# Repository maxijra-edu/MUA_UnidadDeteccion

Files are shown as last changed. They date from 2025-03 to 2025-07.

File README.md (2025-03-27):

# MUA_UnidadDeteccion

Repositorio del proyecto de la Unidad de Detección de la Misión MUA para el GuaraniSat-2, desarrollado en el LME de la FIUNA.

Carpetas:

- Comunicación_Arduino: Contiene el proyecto de platform.io para la comunicación con los componentes digitales de la placa.
- Modelos_3D: Contiene los proyectos FreeCAD (0.21.2) de los modelos de la carcasa, los espaciadores y el ensamble.
- Placa_DetectorParticulas: Proyecto KiCAD (7.0) de la placa principal de la unida de detección.
- Placa_SiPM: Proyecto KiCAD (7.0) del PCB interfaz de los SiPM.

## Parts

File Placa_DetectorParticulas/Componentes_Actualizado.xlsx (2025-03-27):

# | Reference | Qty | Value | Footprint | DNP
1 | C1, C33 | 2 | 0.47uF | Capacitor_SMD:C_0603_1608Metric
2 | C2, C5, C34, C37 | 4 | 1uF | Capacitor_SMD:C_1206_3216Metric
3 | C3, C35 | 2 | 220nF | Capacitor_SMD:C_0603_1608Metric
4 | C4, C36 | 2 | 100nF | Capacitor_SMD:C_0603_1608Metric
5 | C6, C7, C12, C13, C20, C23 | 6 | 10nF | Capacitor_SMD:C_0805_2012Metric
6 | C8, C17 | 2 | 15p | Capacitor_SMD:C_0805_2012Metric
7 | C9, C15, C18, C19, C21, C22, C24, C25, C26, C27, C29, C30, C32, C38, C39, C40, C41, C42, C43, C44, C45, C50, C53, C55 | 24 | 100nF | Capacitor_SMD:C_0805_2012Metric
8 | C10, C16 | 2 | 10u | Capacitor_SMD:C_0805_2012Metric
9 | C11, C14 | 2 | 270p | Capacitor_SMD:C_0805_2012Metric
10 | C28, C31 | 2 | 0.015uF | Capacitor_SMD:C_0805_2012Metric
11 | C46, C47 | 2 | 3p | Capacitor_SMD:C_0805_2012Metric
12 | C48, C49 | 2 | 1uF | Capacitor_SMD:C_0805_2012Metric
13 | C51, C52, C54, C56 | 4 | 6.8uF | Capacitor_SMD:C_0805_2012Metric
14 | D1, D2 | 2 | BAT46 | Diode_SMD:D_SOD-123
15 | D3, D4 | 2 | LED | LED_SMD:LED_0603_1608Metric
16 | J1, J2, J3, J4 | 4 | Conn_02x08_Odd_Even | Connector_PinHeader_2.54mm:PinHeader_2x08_P2.54mm_Vertical
17 | L1, L3 | 2 | 82uH | Inductor_SMD:L_1812_4532Metric
18 | L2, L4 | 2 | 220uH | Inductor_SMD:L_1210_3225Metric
19 | Q1, Q2 | 2 | BSS123 | Package_TO_SOT_SMD:TSOT-23
20 | R1, R44 | 2 | 10k | Resistor_SMD:R_0603_1608Metric
21 | R2, R11, R24, R25, R26, R27, R28, R29, R32, R34, R38, R54, R55, R56, R57, R59, R60, R61, R62, R64, R65 | 21 | 1k | Resistor_SMD:R_0805_2012Metric
22 | R3, R46 | 2 | 392R | Resistor_SMD:R_0603_1608Metric
23 | R4 | 1 | 6.8k | Resistor_SMD:R_0805_2012Metric
24 | R5, R48 | 2 | 240k | Resistor_SMD:R_0603_1608Metric
25 | R6, R15 | 2 | 50 | Resistor_SMD:R_0805_2012Metric
26 | R7, R9, R20, R21 | 4 | 10 | Resistor_SMD:R_0805_2012Metric
27 | R8, R13 | 2 | 5 | Resistor_SMD:R_0805_2012Metric
28 | R10, R12, R72, R73 | 4 | 470 | Resistor_SMD:R_0805_2012Metric
29 | R14 | 1 | 4.53k | Resistor_SMD:R_0805_2012Metric
30 | R16 | 1 | 5.1k | Resistor_SMD:R_0805_2012Metric
31 | R17 | 1 | 68k | Resistor_SMD:R_0805_2012Metric
32 | R18 | 1 | 57.6k | Resistor_SMD:R_0805_2012Metric
33 | R19, R22, R30, R31, R42, R45, R47, R50, R52, R68, R69, R77 | 12 | 10k | Resistor_SMD:R_0805_2012Metric
34 | R23, R35, R39, R53 | 4 | 100k | Resistor_SMD:R_0805_2012Metric
35 | R33, R37 | 2 | 1.5k | Resistor_SMD:R_0805_2012Metric
36 | R36, R40 | 2 | 47 | Resistor_SMD:R_0805_2012Metric
37 | R41, R49, R74, R75, R76, R78 | 6 | 24.9k | Resistor_SMD:R_0603_1608Metric
38 | R43, R51 | 2 | 12.4k | Resistor_SMD:R_0603_1608Metric
39 | R58, R63, R66, R67, R70, R71 | 6 | 0 | Resistor_SMD:R_0805_2012Metric
40 | U1, U20 | 2 | max1932etc+T | 0A_MAX1932:21-0139_T1244&plus_4_MXM
41 | U2, U4 | 2 | OPA855QDSGRQ1 | 0A_OPA855QDSGRQ1:WSON8_DSG_TEX
42 | U3, U5, U9, U23 | 4 | TSZ122IQ2T | 0A_TSZ122IQ2T:DFN8_2X2_NB_STM
43 | U6, U7 | 2 | TS3011IYQ3T | 0A_TS3011IYQ3T:dfn8_2p06x2p06x0p5_stm
44 | U8 | 1 | MCP4561T-104E/MF | DFN8_3x3MC_MCH
45 | U10, U12 | 2 | SN74LV1T04QDCKRQ1 | 0A_SN74LV1T04QDCKRQ1:SC70-5_DCK_TEX
46 | U11, U13 | 2 | 74LVC2G00DP_125 | 0A_74LVC2G00DP-Q100H:SOT765-1_NEX
47 | U14 | 1 | TMP100AQDBVRQ1 | 0A_TMP100AQDBVRQ1:DBV6_TEX
48 | U15, U16 | 2 | ~ | 0A_SiPM_Board:SiPM_Board
49 | U17 | 1 | ~ | 0A_Centellador:Centellador_X2
50 | U18 | 1 | NXS0108BQ-Q100X | 0A_NXS0108BQ-Q100X:DHVQFN20_SOT764-1_NEX
51 | U19 | 1 | NXB0108BQ-Q100X | 0A_NXB0108BQ-Q100X:DHVQFN20_SOT764-1_NEX
52 | U21, U25 | 2 | ADR5044WBRTZ-R7 | 0A_ADR5044WBRTZ-R7:RT_3_ADI
53 | U22, U24 | 2 | INA148QDRQ1 | 0A_INA148QDRQ1:D8
54 | U26, U28 | 2 | DAC8551AQDGKRQ1 | 0A_DAC8551AQDGKRQ1:DGK8_TEX
55 | U27 | 1 | ADR5041WBRTZ-R7 | 0A_ADR5041WBRTZ_R7:RT_3_ADI

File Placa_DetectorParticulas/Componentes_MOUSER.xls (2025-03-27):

SHOPPING CART
This is not an invoice
27-Mar-25 13:32:36
 | Mouser # | Mfr. # | Manufacturer | Customer # | Description | RoHS | Lifecycle | Order Qty. | Price (USD) | Ext.: (USD)
1 | 80-C0805C150J5GAUTO | C0805C150J5GACAUTO | KEMET |  | Multilayer Ceramic Capacitors MLCC - SMD/SMT 50V 15pF C0G 0805 5% AEC-Q200 | RoHS Compliant |  | 10 | $0.101 | $1.01
2 | 80-C0805C200J1HAUTO | C0805C200J1HACAUTO | KEMET |  | Multilayer Ceramic Capacitors MLCC - SMD/SMT 100V 20pF X8R 0805 5% AEC-Q200 | RoHS Compliant |  | 10 | $0.053 | $0.53
3 | 81-GCM188R71C474KA5J | GCM188R71C474KA55J | Murata |  | Multilayer Ceramic Capacitors MLCC - SMD/SMT 0.47 uF 16 VDC 10% 0603 X7R AEC-Q200 | RoHS Compliant |  | 10 | $0.089 | $0.89
4 | 963-HMK316B7105KLHT | HMK316B7105KLHT | TAIYO YUDEN |  | Multilayer Ceramic Capacitors MLCC - SMD/SMT 963-MCASH31LSB7105KT RPLCMT PN 100V 1uF X7R 1206 AEC-Q200 | RoHS Compliant |  | 10 | $0.241 | $2.41
5 | 963-MAASU168AC7224KT | MAASU168AC7224KTCA01 | TAIYO YUDEN |  | Multilayer Ceramic Capacitors MLCC - SMD/SMT 50V 0.22uF X7S 0603 10% AEC-Q200 | RoHS Compliant |  | 10 | $0.124 | $1.24
6 | 581-KAM15AR71H104KM | KAM15AR71H104KM | KYOCERA AVX |  | Multilayer Ceramic Capacitors MLCC - SMD/SMT 50V .1uF X7R 0603 10 % AEC-Q200 | RoHS Compliant | New Product | 20 | $0.264 | $5.28
7 | 581-KAF21BR72A103JT | KAF21BR72A103JT | KYOCERA AVX |  | Multilayer Ceramic Capacitors MLCC - SMD/SMT 100V .01uF X7R 0805 5% AEC-Q200 FLEXITER | RoHS Compliant | New Product | 10 | $0.195 | $1.95
8 | 581-KAM21BR71H104JT | KAM21BR71H104JT | KYOCERA AVX |  | Multilayer Ceramic Capacitors MLCC - SMD/SMT 50V .1uF X7R 0805 5% AEC-Q200 | RoHS Compliant | New Product | 40 | $0.208 | $8.32
9 | 810-CGA4J1X7R0J106K | CGA4J1X7R0J106K125AC | TDK |  | Multilayer Ceramic Capacitors MLCC - SMD/SMT CGA 0805 6.3V 10uF X7R 10% AEC-Q200 | RoHS Compliant |  | 16 | $0.18 | $2.88
10 | 80-C0805C271J5GAUTO | C0805C271J5GACAUTO | KEMET |  | Multilayer Ceramic Capacitors MLCC - SMD/SMT 50V 270pF C0G 0805 5% AEC-Q200 | RoHS Compliant |  | 10 | $0.202 | $2.02
11 | 80-C0805C153J5RAUTO | C0805C153J5RACAUTO | KEMET |  | Multilayer Ceramic Capacitors MLCC - SMD/SMT 50V 0.015uF X7R 0805 5% AEC-Q200 | RoHS Compliant |  | 10 | $0.276 | $2.76
12 | 80-C0603C309C4HAUTO | C0603C309C4HACAUTO | KEMET |  | Multilayer Ceramic Capacitors MLCC - SMD/SMT 16V 3pF 0603 X8R 0.25pF AEC-Q200 | RoHS Compliant |  | 10 | $0.057 | $0.57
13 | 581-KAM21KR72A105KU | KAM21KR72A105KU | KYOCERA AVX |  | Multilayer Ceramic Capacitors MLCC - SMD/SMT 100V 1uF X7R 0805 10 % AEC-Q200 | RoHS Compliant | New Product | 10 | $0.309 | $3.09
14 | 810-CGA4J1X5R1C685KC | CGA4J1X5R1C685K125AC | TDK |  | Multilayer Ceramic Capacitors MLCC - SMD/SMT CGA 0805 16V 6.8uF X5R 10% AEC-Q200 | RoHS Compliant |  | 10 | $0.267 | $2.67
15 | 78-BAT46W-HE3-08 | BAT46W-HE3-08 | Vishay |  | Schottky Diodes & Rectifiers 100Volt 150mA 750mA AUTO | RoHS Compliant | End of Life | 10 | $0.193 | $1.93
16 | 81-LQH43NH820J03L | LQH43NH820J03L | Murata |  | RF Inductors - SMD | RoHS Compliant |  | 4 | $0.71 | $2.84
17 | 871-B82422H1224K | B82422H1224K000 | TDK |  | RF Inductors - SMD 220uH 100mA 10% 3.2x2.5mm SMD | RoHS Compliant |  | 10 | $0.482 | $4.82
18 | 726-BSS123NH6327 | BSS123N H6327 | Infineon |  | MOSFETs N-Ch 100V 190mA SOT-23-3 | RoHS Compliant |  | 10 | $0.27 | $2.70
19 | 667-ERA-3AEB103V | ERA-3AEB103V | Panasonic |  | Thin Film Resistors - SMD 0603 1/10W 10Kohms 0.1% 25ppm | RoHS Compliant By Exemption |  | 10 | $0.058 | $0.58
20 | 71-CRCW0603-392-E3 | CRCW0603392RFKEA | Vishay |  | Thick Film Resistors - SMD 1/10watt 392ohms 1% | RoHS Compliant |  | 10 | $0.017 | $0.17
21 | 667-ERJ-3GEYJ244V | ERJ-3GEYJ244V | Panasonic |  | Thick Film Resistors - SMD 0603 240Kohms 5% AEC-Q200 | RoHS Compliant By Exemption |  | 10 | $0.012 | $0.12
22 | 71-RCS060324K9FKEA | RCS060324K9FKEA | Vishay |  | Thick Film Resistors - SMD .25watt 24.9Kohm 1% AEC-Q200 | RoHS Compliant By Exemption |  | 10 | $0.052 | $0.52
23 | 667-ERA-3AEB153V | ERA-3AEB153V | Panasonic |  | Thin Film Resistors - SMD 0603 15Kohm 1/10W AEC-Q200 | RoHS Compliant By Exemption |  | 10 | $0.058 | $0.58
24 | 71-CRCW0603-12.4K-E3 | CRCW060312K4FKEA | Vishay |  | Thick Film Resistors - SMD 1/10watt 12.4Kohms 1% | RoHS Compliant By Exemption |  | 10 | $0.017 | $0.17
25 | 71-CRCW0603-12.7K-E3 | CRCW060312K7FKEA | Vishay |  | Thick Film Resistors - SMD 1/10watt 12.7Kohms 1% | RoHS Compliant By Exemption |  | 10 | $0.015 | $0.15
26 | 667-ERJ-U06F1001V | ERJ-U06F1001V | Panasonic |  | Thick Film Resistors - SMD 0805 1% 1.0Kohm Anti-Sulfur AEC-Q200 | RoHS Compliant By Exemption |  | 60 | $0.05 | $3.00
27 | 667-ERA-6AED682V | ERA-6AED682V | Panasonic |  | Thin Film Resistors - SMD 0805 6800ohms 25ppm 0.5% AEC-Q200 | RoHS Compliant By Exemption |  | 10 | $0.187 | $1.87
28 | 71-CRCW0805-50 | CRCW080550R0FKTA | Vishay |  | Thick Film Resistors - SMD 1/8watt 50ohms 1% Non Std Qt Req'd | No |  | 10 | $0.082 | $0.82
29 | 603-AC0805FR-1310RL | AC0805FR-1310RL | YAGEO |  | Thick Film Resistors - SMD 10 Ohms 1/8 Wa 0805 1% AEC-Q200 | RoHS Compliant By Exemption |  | 10 | $0.034 | $0.34
30 | 71-CRCW08055R10FKEA | CRCW08055R10FKEA | Vishay |  | Thick Film Resistors - SMD 1/8watt 5.1ohms 1% | RoHS Compliant By Exemption |  | 10 | $0.043 | $0.43
31 | 667-ERA-6AEB471V | ERA-6AEB471V | Panasonic |  | Thin Film Resistors - SMD 0805 1/8W 470ohms | RoHS Compliant By Exemption |  | 10 | $0.058 | $0.58
32 | 667-ERA-6AEB4531V | ERA-6AEB4531V | Panasonic |  | Thin Film Resistors - SMD 0805 4.53Kohm 0.1% 25ppm | RoHS Compliant By Exemption |  | 10 | $0.058 | $0.58
33 | 71-CRCW080512K0FKEA | CRCW080512K0FKEA | Vishay |  | Thick Film Resistors - SMD 1/8watt 12Kohms 1% 100ppm | RoHS Compliant By Exemption |  | 10 | $0.029 | $0.29
34 | 667-ERJ-6ENF6802V | ERJ-6ENF6802V | Panasonic |  | Thick Film Resistors - SMD 0805 68Kohms 1% AEC-Q200 | RoHS Compliant By Exemption |  | 10 | $0.034 | $0.34
35 | 667-ERJ-P06F3302V | ERJ-P06F3302V | Panasonic |  | Thick Film Resistors - SMD 0805 33Kohms 0.5W 1% AEC-Q200 | RoHS Compliant By Exemption |  | 10 | $0.061 | $0.61
36 | 71-CRCW080551K0FKEA | CRCW080551K0FKEA | Vishay |  | Thick Film Resistors - SMD 1/8watt 51Kohms 1% | RoHS Compliant By Exemption |  | 10 | $0.029 | $0.29
37 | 71-CRCW0805-10K-E3 | CRCW080510K0FKEA | Vishay |  | Thick Film Resistors - SMD 1/8watt 10Kohms 1% 100ppm | RoHS Compliant By Exemption |  | 40 | $0.042 | $1.68
38 | 667-ERJ-6ENF1003V | ERJ-6ENF1003V | Panasonic |  | Thick Film Resistors - SMD 0805 100Kohms 1% AEC-Q200 | RoHS Compliant By Exemption |  | 10 | $0.047 | $0.47
39 | 71-CRCW0805-1.5K-E3 | CRCW08051K50FKEA | Vishay |  | Thick Film Resistors - SMD 1/8watt 1.5Kohms 1% 100ppm | RoHS Compliant By Exemption |  | 10 | $0.035 | $0.35
40 | 71-CRCW080547R0FKEAH | CRCW080547R0FKEAHP | Vishay |  | Thick Film Resistors - SMD 1/2watt 47ohms 1% High Power AEC-Q200 | RoHS Compliant By Exemption |  | 10 | $0.089 | $0.89
41 | 71-CRCW08050000Z0EC | CRCW08050000Z0EC | Vishay |  | Thick Film Resistors - SMD ZERO OHM JUMPER | RoHS Compliant By Exemption |  | 20 | $0.02 | $0.40
42 | 700-MAX1932ETCT | MAX1932ETC+T | Analog Devices Inc. |  | Power Management Specialized - PMIC Digitally Controlled, 0.5 Accurate, Saf | RoHS Compliant |  | 2 | $14.64 | $29.28
43 | 595-OPA855QDSGRQ1 | OPA855QDSGRQ1 | Texas Instruments |  | High Speed Operational Amplifiers Automotive 8-GHz gai n bandwidth decompe | RoHS Compliant |  | 2 | $6.73 | $13.46
44 | 511-TSZ122IQ2T | TSZ122IQ2T | STMicroelectronics |  | Precision Amplifiers Very high accuracy 0 drift micropowr 5V | RoHS Compliant |  | 4 | $1.26 | $5.04
45 | 511-TS3011IYQ3T | TS3011IYQ3T | STMicroelectronics |  | Analog Comparators Rail-to-rail high-speed comparator | RoHS Compliant |  | 2 | $2.22 | $4.44
46 | 579-MCP4561T-104E/MF | MCP4561T-104E/MF | Microchip |  | Digital Potentiometer ICs Sngl 8B NV I2C POT | RoHS Compliant |  | 1 | $1.27 | $1.27
47 | 595-N74LV1T04QDCKRQ1 | SN74LV1T04QDCKRQ1 | Texas Instruments |  | Translation - Voltage Levels Automotive single po wer supply inverter | RoHS Compliant | New Product | 2 | $0.33 | $0.66
48 | 771-74LVC2G00DCQ100H | 74LVC2G00DC-Q100H | Nexperia |  | Logic Gates Dual 2-input NAND gate | RoHS Compliant |  | 2 | $0.47 | $0.94
49 | 595-TMP100AQDBVRQ1 | TMP100AQDBVRQ1 | Texas Instruments |  | Board Mount Temperature Sensors Temperature Sensor W ith I2C and SMBus In | RoHS Compliant |  | 1 | $2.11 | $2.11
50 | 771-NXS0108BQ-Q100X | NXS0108BQ-Q100X | Nexperia |  | Translation - Voltage Levels Dual supply translating transceiver; open drain; auto directionsensing | RoHS Compliant By Exemption |  | 1 | $1.01 | $1.01
51 | 771-NXB0108BQ-Q100X | NXB0108BQ-Q100X | Nexperia |  | Translation - Voltage Levels Dual supply translating transceiver; auto direction sensing; 3-state | RoHS Compliant By Exemption |  | 1 | $1.01 | $1.01
52 | 584-ADR5044WBRTZ-R7 | ADR5044WBRTZ-R7 | Analog Devices Inc. |  | Voltage References 4.096V Shunt Voltage Ref | RoHS Compliant |  | 2 | $1.96 | $3.92
53 | 595-INA148QDRQ1 | INA148QDRQ1 | Texas Instruments |  | Differential Amplifiers Auto Cat +-200V Com- Mode Vltg Diff Amp | RoHS Compliant |  | 2 | $5.53 | $11.06
54 | 855-R20-1000602 | R20-1000602 | Harwin |  | Standoffs & Spacers M2 x 6mm HEXAGONAL BRASS 4.9mm A/F | RoHS Compliant By Exemption |  | 10 | $0.306 | $3.06
55 | 667-ERA-6AEB5762V | ERA-6AEB5762V | Panasonic |  | Thin Film Resistors - SMD 0805 57.6Kohm 0.1% 25ppm | RoHS Compliant By Exemption |  | 10 | $0.058 | $0.58
56 | 667-ERA-6AEB103V | ERA-6AEB103V | Panasonic |  | Thin Film Resistors - SMD 0805 1/8W 10Kohms | RoHS Compliant By Exemption |  | 20 | $0.058 | $1.16
57 | 667-ERA-6AED683V | ERA-6AED683V | Panasonic |  | Thin Film Resistors - SMD 0805 68Kohms 25ppm 0.5% AEC-Q200 | RoHS Compliant By Exemption |  | 10 | $0.187 | $1.87
58 | 667-ERA-6AEB123V | ERA-6AEB123V | Panasonic |  | Thin Film Resistors - SMD 0805 1/8W 12Kohms | RoHS Compliant By Exemption |  | 10 | $0.059 | $0.59
59 | 667-ERA-6AED512V | ERA-6AED512V | Panasonic |  | Thin Film Resistors - SMD 0805 5100ohms 25ppm 0.5% AEC-Q200 | RoHS Compliant By Exemption |  | 10 | $0.122 | $1.22
60 | 667-ERA-6ARB102V | ERA-6ARB102V | Panasonic |  | Thin Film Resistors - SMD 0805 1Kohm 0.1% 10ppm AEC-Q200 |  |  | 10 | $0.359 | $3.59
61 | 603-RP0805BRD07100KL | RP0805BRD07100KL | YAGEO |  | Thin Film Resistors - SMD 1/8 Wa 100K Ohm 0.1% 0805 AEC-Q200 | RoHS Compliant |  | 10 | $0.157 | $1.57
62 | 667-ERA-3AEB2492V | ERA-3AEB2492V | Panasonic |  | Thin Film Resistors - SMD 0603 24.9Kohm 0.1% 25ppm | RoHS Compliant By Exemption |  | 20 | $0.058 | $1.16
63 | 71-TNPW0603240KBEEA | TNPW0603240KBEEA | Vishay |  | Thin Film Resistors - SMD 240Kohms .1% 25ppm | RoHS Compliant |  | 10 | $0.271 | $2.71
64 | 71-TNPW060312K4BEEA | TNPW060312K4BEEA | Vishay |  | Thin Film Resistors - SMD 12.4Kohms .1% 25ppm | RoHS Compliant |  | 10 | $0.205 | $2.05
65 | 667-ERA-3AEB1272V | ERA-3AEB1272V | Panasonic |  | Thin Film Resistors - SMD 0603 12.7Kohm 0.1% 25ppm | RoHS Compliant By Exemption |  | 10 | $0.058 | $0.58
66 | 720-KBDELPS212A6350 | KB DELPS2.12-QHRI-24-Z555 | ams OSRAM |  | Single Color LEDs KB DELPS2.12 | RoHS Compliant |  | 10 | $0.158 | $1.58
67 | 595-DAC8551AQDGKRQ1 | DAC8551AQDGKRQ1 | Texas Instruments |  | Digital to Analog Converters - DAC DAC8551-Q1 Automotiv e 16-Bit Ultralow-G | RoHS Compliant |  | 2 | $6.95 | $13.90
68 | 584-ADR5041WBRTZ-R7 | ADR5041WBRTZ-R7 | Analog Devices Inc. |  | Voltage References 2.5V Shunt Voltage Ref | RoHS Compliant |  | 2 | $2.97 | $5.94
By submitting your order you agree to these terms and conditions. (https://www.mouser.com/saleterms) |  |  |  |  |  |  |  |  | Merchandise: | $178.90
Prices are reflected at the date and time shown. |  |  |  |  |  |  |  |  | Shipping Charge: | $8.89
 |  |  |  |  |  |  |  |  | Backorder Shipping: | $1.99

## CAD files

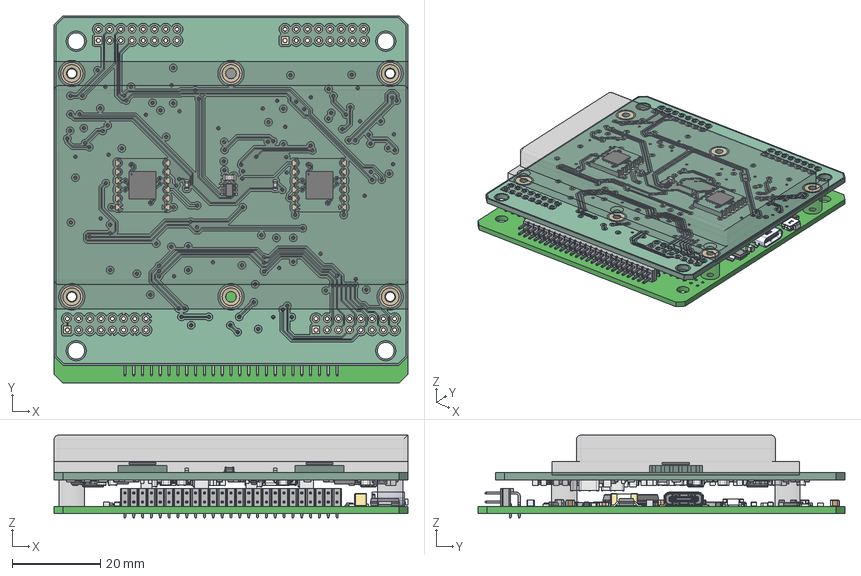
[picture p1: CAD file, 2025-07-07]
Modelos_3D/MUA_AssemblyV2.FCStd
80.0 x 83.0 x 18.7 mm
Pcb_d980
topPads_d980
topPads_d981
topPads_d982
topPads_d983
topPads_d984
topPads_d985
topPads_d986
topPads_d987
topPads_d988
topPads_d989
topPads_d990
topPads_d991
topPads_d992
topPads_d993
topPads_d994
topPads_d995
topPads_d996
topPads_d997
topPads_d998
topPads_d999
topPads_d1000
topPads_d1001
topPads_d1002
topPads_d1003
topPads_d1004
topPads_d1005
topPads_d1006
topPads_d1007
topPads_d1008
topPads_d1009
topPads_d1010
topPads_d1011
topPads_d1012
topPads_d1013
topPads_d1014
topPads_d1015
topPads_d1016
topPads_d1017
topPads_d1018
topPads_d1019
topPads_d1020
topPads_d1021
topPads_d1022
topPads_d1023
topPads_d1024
topPads_d1025
topPads_d1026
topPads_d1027
topPads_d1028
topPads_d1029
topPads_d1030
topPads_d1031
topPads_d1032
topPads_d1033
topPads_d1034
topPads_d1035
topPads_d1036
topPads_d1037
topPads_d1038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

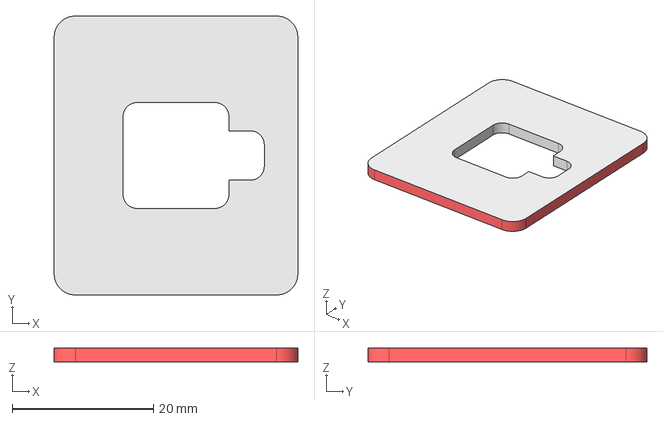
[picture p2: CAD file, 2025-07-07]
Modelos_3D/SpacerRedondeado.step
34.5 x 39.5 x 2.00 mm

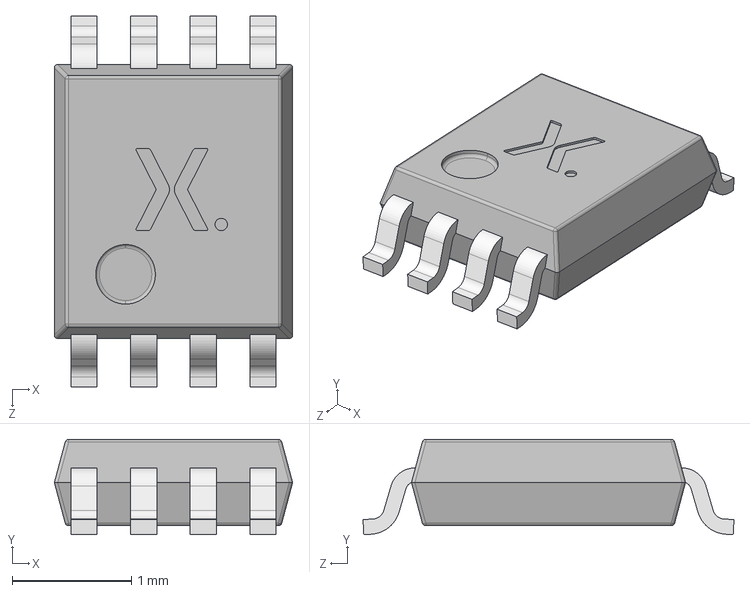
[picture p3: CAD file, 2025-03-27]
Placa_DetectorParticulas/Componentes/74LVC2G00DP-Q100H/SOT765-1.step
2.00 x 0.8 x 3.11 mm
SOT765 Mold body
SOT765 Lead x 8

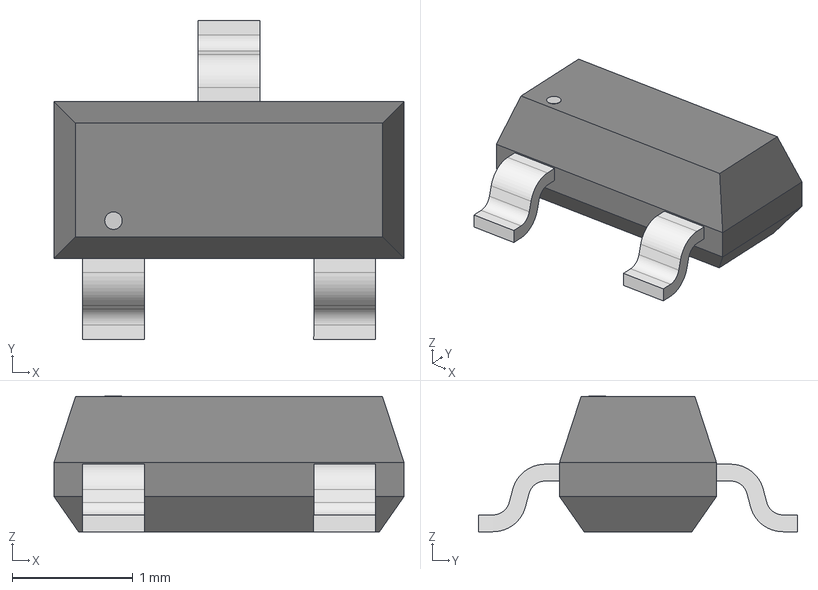
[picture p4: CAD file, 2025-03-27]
Placa_DetectorParticulas/Componentes/ADR5041WBRTZ_R7/RT_3_ADI.step
2.90 x 2.64 x 1.12 mm

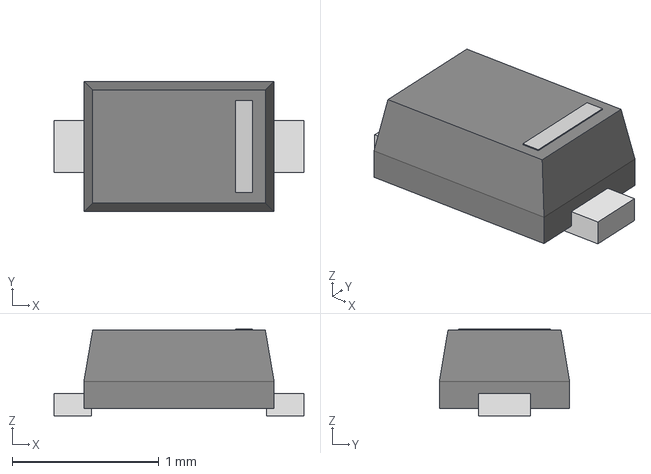
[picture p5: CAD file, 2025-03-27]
Placa_DetectorParticulas/Componentes/BAS5202VH6327/CR_SC79_INF.step
1.70 x 0.888 x 0.591 mm

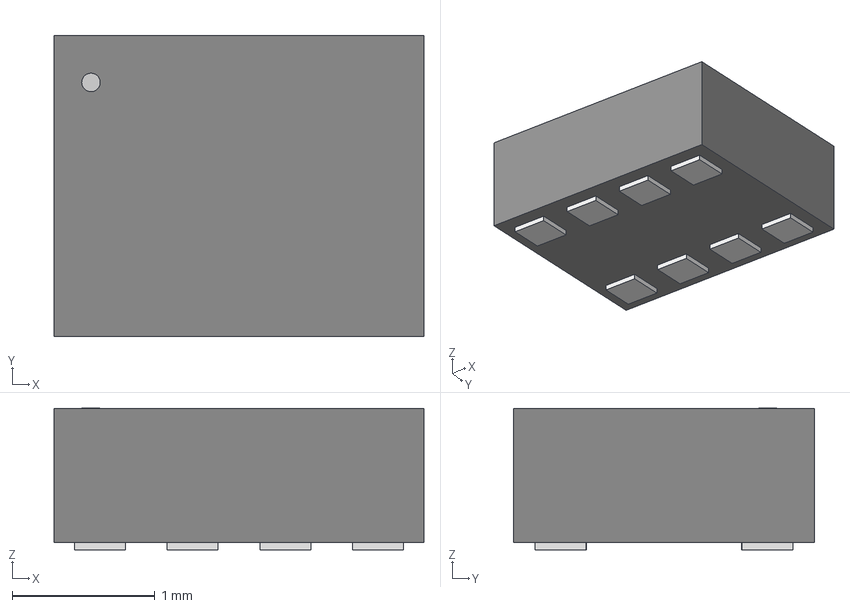
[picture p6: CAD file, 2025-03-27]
Placa_DetectorParticulas/Componentes/BMP280/LGA8_BMP280_BOS.step
2.59 x 2.11 x 0.993 mm

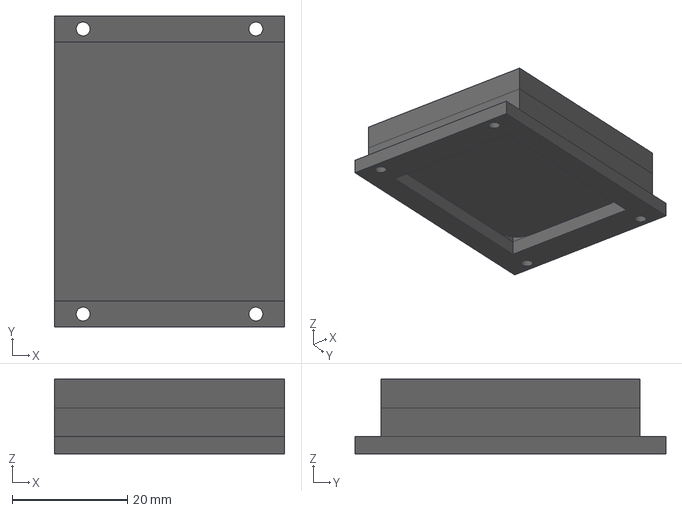
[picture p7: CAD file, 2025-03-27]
Placa_DetectorParticulas/Componentes/Centellador/Centellador-Cuerpo.step
40.0 x 54.0 x 13.0 mm
Cuerpo
Cuerpo002

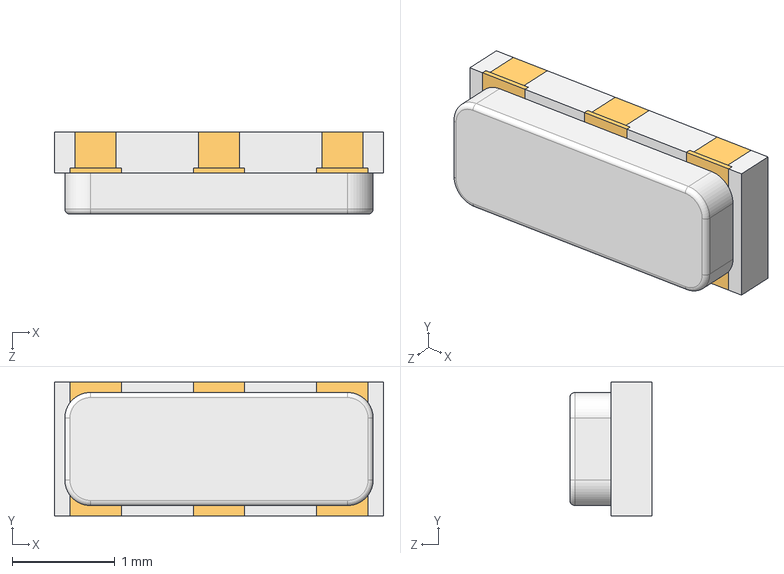
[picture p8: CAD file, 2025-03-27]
Placa_DetectorParticulas/Componentes/CSTNE12M0GH5L000R0/CSTNE12M0GH5L000R0.stp
3.20 x 1.30 x 0.8 mm

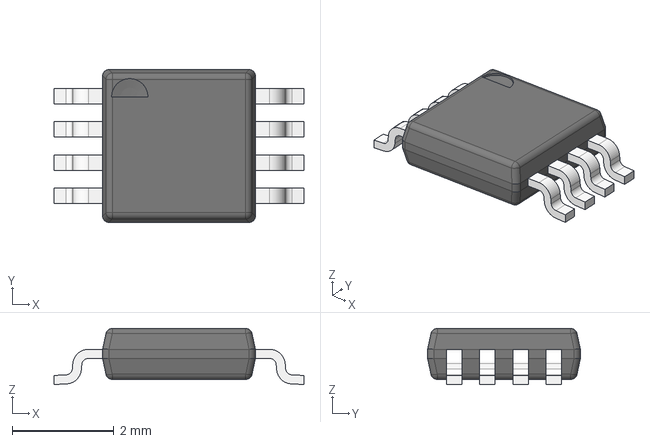
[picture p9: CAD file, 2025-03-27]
Placa_DetectorParticulas/Componentes/DAC8551AQDGKRQ1/DGK0008A.stp
4.90 x 3.00 x 1.10 mm
BODY_MUA08A
LEAD_MUA08A x 8

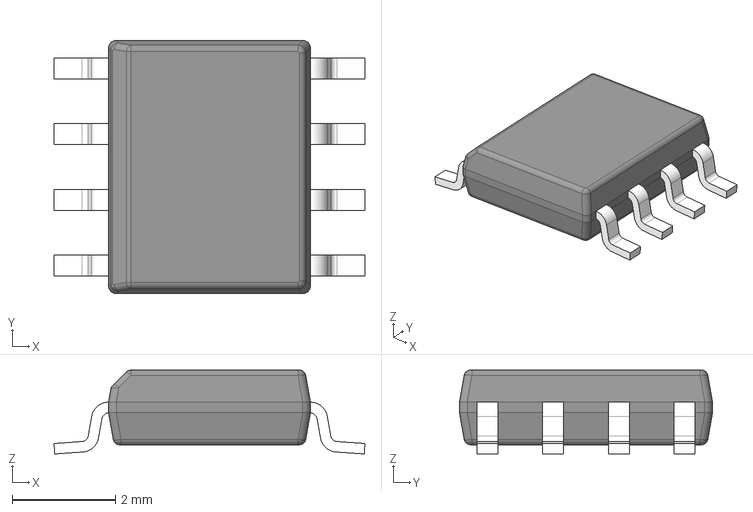
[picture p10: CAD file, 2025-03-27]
Placa_DetectorParticulas/Componentes/INA148QDRQ1/D0008A.stp
6.02 x 4.90 x 1.63 mm
BODY-SO
LEAD-D0008A x 8

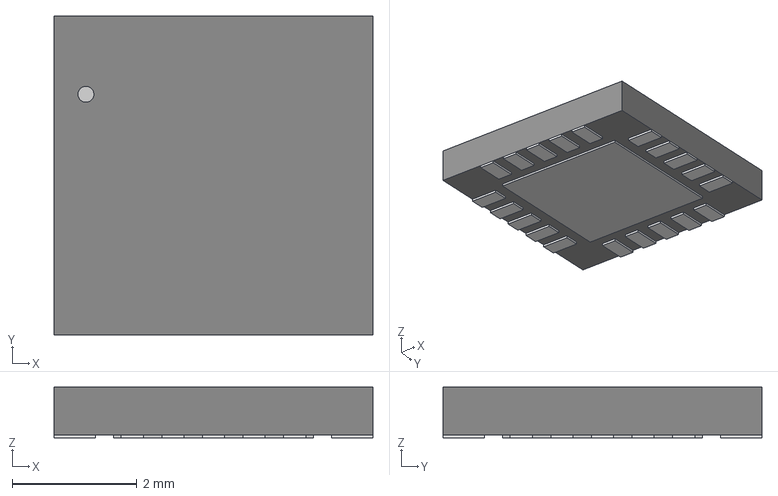
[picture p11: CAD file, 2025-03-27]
Placa_DetectorParticulas/Componentes/MAX14778ETP/21-0140_T20554C_MXM.step
5.11 x 5.11 x 0.815 mm

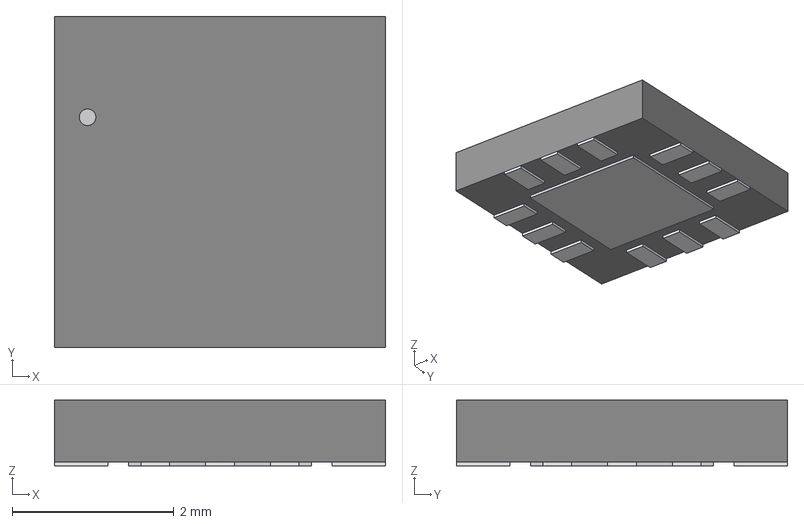
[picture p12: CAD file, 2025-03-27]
Placa_DetectorParticulas/Componentes/MAX1932/21-0139_T12444_MXM.step
4.09 x 4.09 x 0.815 mm

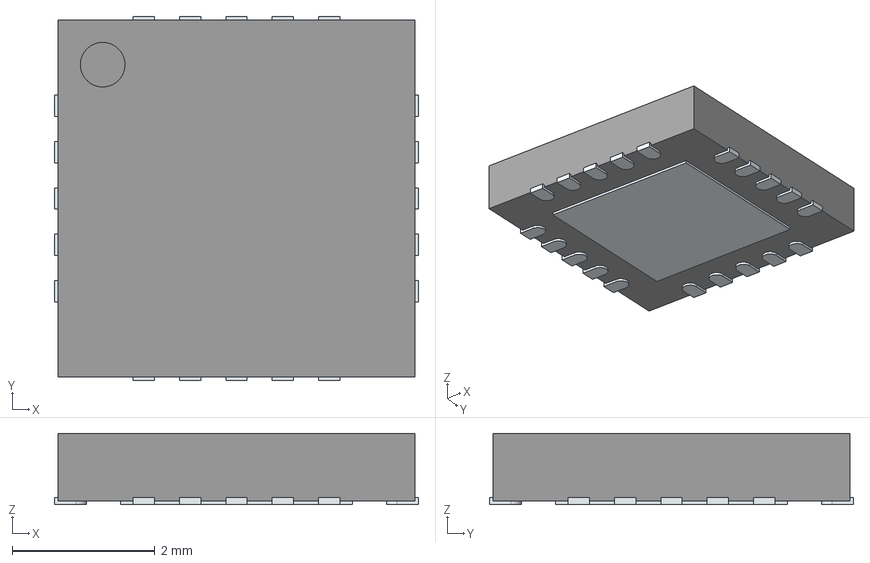
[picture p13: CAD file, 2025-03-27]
Placa_DetectorParticulas/Componentes/MCP2210T-I_MQ/MCP2210T-I_MQ.stp
5.10 x 5.10 x 1.00 mm
ThermalPin
PinsArrayLR
PinsArrayTB

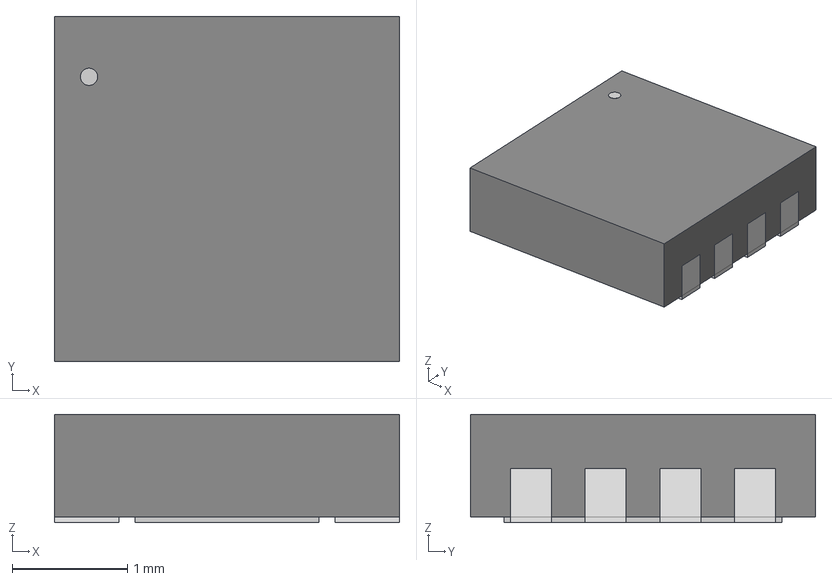
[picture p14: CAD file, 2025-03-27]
Placa_DetectorParticulas/Componentes/MCP4561T_103E_MF/DFN8_3x3MC_MCH.step
3.00 x 3.00 x 0.942 mm

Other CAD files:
Placa_DetectorParticulas/Componentes/ADR5044WBRTZ-R7/RT_3_ADI.step
Placa_DetectorParticulas/Componentes/MCP4561T_104E_MF/DFN8_3x3MC_MCH.step
Placa_DetectorParticulas/Componentes/MCP4661T_104E_ML/QFN16_4x4MC_MCH.step
Placa_DetectorParticulas/Componentes/MICROFJ-60035-TSV-TR1/MICROFJ-60035-TSV_ONS.step
Modelos_3D/CarcasaV3.FCStd
Modelos_3D/CarcasaV3.step
Modelos_3D/CarcasaV3.stl
Modelos_3D/CarcasaV3Final.step
Modelos_3D/CarcasaV3Final.stl
Modelos_3D/CarcasaV3L.step
Modelos_3D/CarcasaV3L.stl
Modelos_3D/CarcasaV3Threaded.step
Modelos_3D/CarcasaV3Threaded.stl
Modelos_3D/PlacaCarcasaV3.FCStd
Modelos_3D/Spacer.FCStd
Modelos_3D/Spacer.stl
Modelos_3D/SpacerRedondeado.stl
Placa_DetectorParticulas/Componentes/74LVC2G00DP-Q100H/TSSOP8_SOT505-2_NEX.step
Placa_DetectorParticulas/Componentes/74LVC2G00DP-Q100H/TSSOP8_SOT505-2_NEX.stl
Placa_DetectorParticulas/Componentes/ADR5044WBRTZ-R7/RT_3_ADI.stl
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

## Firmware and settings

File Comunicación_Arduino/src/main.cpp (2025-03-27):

#include<Arduino.h>
#include"Comunicacion.h"
#ifdef __xtensa__
  #include<driver/adc.h>
  #define adcB 4095
  #define VREF 3.1
#endif
#ifdef __AVR__
  #define adcB 1023
  #define VREF 5.0
#endif
#define LED1 2
#define LED2 3

//#include<Arduino_FreeRTOS.h>

uint32_t Tiempo = 0;
uint16_t ciclos = 0;
uint16_t serialRegs[5] = { uint16_t(0.625*255/1.25), uint16_t(0.625*255/1.25), uint16_t(0.625/2.5*65535), uint16_t(0.625/2.5*65535), uint16_t(2.5*256/4.096) };
byte serialAddress = 0;
byte serialBuffer[2] = {0,0};

void setup() {
  // Comunicación
  Wire.begin();
  Wire.setClock(400000);
  Serial.begin(115200);
  SPI.begin();
  // Pines
  #ifdef __xtensa__
    adc1_config_channel_atten(ADC1_CHANNEL_0, ADC_ATTEN_DB_12);
    adc1_config_channel_atten(ADC1_CHANNEL_1, ADC_ATTEN_DB_12);
    adc1_config_channel_atten(ADC1_CHANNEL_2, ADC_ATTEN_DB_12);
    pinMode(LED_RED,OUTPUT);
    pinMode(LED_GREEN,OUTPUT);
    pinMode(LED_BLUE,OUTPUT);
  #endif
  pinMode(A0,INPUT);
  pinMode(A1,INPUT);
  pinMode(A2,INPUT);
  pinMode(A3,INPUT);
  digitalWrite(MAX1_CS,HIGH);
  digitalWrite(DAC1_CS,HIGH);
  digitalWrite(MAX2_CS,HIGH);
  digitalWrite(DAC2_CS,HIGH);
  digitalWrite(LED1, LOW);
  digitalWrite(LED2, LOW);
  pinMode(MAX1_CS,OUTPUT);
  pinMode(DAC1_CS,OUTPUT);
  pinMode(MAX2_CS,OUTPUT);
  pinMode(DAC2_CS,OUTPUT);
  pinMode(LED1,OUTPUT);
  pinMode(LED2,OUTPUT);

  #ifdef __xtensa__
    analogWrite(LED_RED,192);
    analogWrite(LED_GREEN,255);
    analogWrite(LED_BLUE,255);
  #endif
  
  delay(1000);
  
  #ifdef __xtensa__
    analogWrite(LED_RED,255);
    analogWrite(LED_GREEN,192);
    analogWrite(LED_BLUE,255);
  #endif
  
  Tiempo = millis()+1000;
  Serial.println("Inicio");
}

void loop() {
  if(Serial.available()==3)
  {
    #ifdef __xtensa__
      analogWrite(LED_RED,192);
      analogWrite(LED_GREEN,255);
      analogWrite(LED_BLUE,255);
    #endif
    serialAddress = Serial.read();
    Serial.readBytes(&serialBuffer[0],2);
    if(serialAddress<6)
    {
      serialRegs[serialAddress] = uint16_t(serialBuffer[0]*256+uint16_t(serialBuffer[1]));
      Serial.print("Se escribió el valor ");
      Serial.print(serialRegs[serialAddress],HEX);
      Serial.println(" en la memoria.");
    }
    if(serialRegs[0]>255){ serialRegs[0]=255; }
    if(serialRegs[1]>255){ serialRegs[1]=255; }
    if(serialRegs[4]>256){ serialRegs[4]=256; }
    #ifdef __xtensa__
      analogWrite(LED_RED,255);
      analogWrite(LED_GREEN,192);
      analogWrite(LED_BLUE,255);
    #endif
  }

  if(millis()>Tiempo)
  {
    #ifdef __xtensa__
      analogWrite(LED_RED,255);
      analogWrite(LED_GREEN,255);
      analogWrite(LED_BLUE,192);
    #endif
    Tiempo = millis()+5000;
    ciclos = ciclos + 1;
    //Se limpia la ventana de la terminal
    Serial.write(27);
    Serial.print("[2J");
    Serial.write(27);
    Serial.print("[H");
    //Se imprimen los datos
    Serial.print("Ciclo N°");
    Serial.println(ciclos);
    //Se lee la temperatura
    float Tem = MUA::leerTemperatura(12);
    Serial.print("Temperatura = ");
    Serial.print(Tem);
    Serial.println("°C.");
    if(Tem>40){ Tem = 40; }
    if(Tem<20){ Tem = 20; }

    MUA::escribirMAX(serialRegs[0], MAX1_CS);
    Serial.print ("Se escribió el valor 0x");
    Serial.print(serialRegs[0],HEX);
    Serial.print(" al MAX1, que equivale a ");
    float DACMAX1 = 1.25*serialRegs[0]/255;
    Serial.print(DACMAX1, 4);
    Serial.println("V en su DAC.");

    MUA::escribirMAX(serialRegs[1], MAX2_CS);
    Serial.print ("Se escribió el valor 0x");
    Serial.print(serialRegs[1],HEX);
    Serial.print(" al MAX2, que equivale a ");
    float DACMAX2 = 1.25*serialRegs[1]/255;
    Serial.print(DACMAX2, 4);
    Serial.println("V en su DAC.");

    MUA::escribirDAC(serialRegs[2], DAC1_CS);
    Serial.print ("Se escribió el valor 0x");
    Serial.print(serialRegs[2],HEX);
    Serial.print(" al DAC1, que equivale a ");
    float DACDAC1 = serialRegs[2]*2.5/65535;
    Serial.print(DACDAC1, 4);
    Serial.println("V.");

    MUA::escribirDAC(serialRegs[3], DAC2_CS);
    Serial.print ("Se escribió el valor 0x");
    Serial.print(serialRegs[3],HEX);
    Serial.print(" al DAC2, que equivale a ");
    float DACDAC2 = serialRegs[3]*2.5/65535;
    Serial.print(DACDAC2, 4);
    Serial.println("V.");

    Serial.print("El MAX1 debe tener en su salida un valor de ");
    Serial.print( 240/12.7*(1.25-0) + 240/24.9*(1.25-DACMAX1) + 240/24.9*(1.25-DACDAC1) + 240/24.9*(-1.25), 4 );
    Serial.println("V.");

    Serial.print("El MAX2 debe tener en su salida un valor de ");
    Serial.print( 240/12.7*(1.25-0) + 240/24.9*(1.25-DACMAX2) + 240/24.9*(1.25-DACDAC2) + 240/24.9*(-1.25), 4 );
    Serial.println("V.");

    MUA::escribirPotenciometro(serialRegs[4]);
    Serial.print ("Se escribió el valor 0x");
    Serial.print(serialRegs[4],HEX);
    Serial.print(" al Potenciómetro, que equivale a ");
    Serial.print(serialRegs[4]*4.096/256, 4);
    Serial.println("V.");

    #ifdef __xtensa__
      analogWrite(LED_RED,255);
      analogWrite(LED_GREEN,192);
      analogWrite(LED_BLUE,255);
    #endif

    delay(1000);
    Serial.print(".");
    digitalWrite(LED1,HIGH);
    digitalWrite(LED1,LOW);
    digitalWrite(LED2,HIGH);
    digitalWrite(LED2,LOW);
    delay(1000);
    Serial.print(".");
    delay(1000);
    Serial.println(".");
  }
}

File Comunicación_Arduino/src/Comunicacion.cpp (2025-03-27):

#include"Comunicacion.h"
#include<Arduino.h>
#define byte uint8_t
byte data[2] = {0x00, 0x00};

float MUA::leerTemperatura()
{
  data[0] = 0x00;
  data[1] = 0x00;
  Wire.beginTransmission(int(TMP100)); //Dirección del TMP100
  Wire.write(0x00);
  Wire.endTransmission(true);
  Wire.requestFrom(int(TMP100), 2);
  for (int i = 0; i < 2; ++i) {
    if (Wire.available()) {
      data[i] = Wire.read();
    }
  }
  int16_t temp = int(data[0]);
  temp = temp * 256;
  temp = temp + (unsigned int)(data[1]);
  temp = temp / 16;
  float T = 0;
  T = 256.0 * (temp + 2048.0) / 4095.0 - 128;
  return T;
}

float MUA::leerTemperatura(int bits)
{
  //Se encienden las mediciones
  Wire.beginTransmission(TMP100); //Dirección del TMP100
  Wire.write(0x01);
  if(bits==9)      { Wire.write(0b00000000); Wire.endTransmission(true);}
  else if(bits==10){ Wire.write(0b00100000); Wire.endTransmission(true);}
  else if(bits==11){ Wire.write(0b01000000); Wire.endTransmission(true);}
  else if(bits==12){ Wire.write(0b01100000); Wire.endTransmission(true);}
  else { Wire.endTransmission(true); return -1; }
  delay(800);
  //Se inicia la lectura del valor
  Wire.beginTransmission(TMP100); //Dirección del TMP100
  Wire.write(0x00);
  Wire.endTransmission(true);
  data[0] = 0x00;
  data[1] = 0x00;
  Wire.requestFrom(TMP100, 2);
  delay(10);
  data[0] = 0x00;
  data[1] = 0x00;
  Wire.requestFrom(TMP100, 2);

  //Entra en estado de reposo.
  Wire.beginTransmission(int(TMP100)); //Dirección del TMP100
  Wire.write(0x01);
  Wire.write(0b00000001);
  Wire.endTransmission(true);
    
  for (int i = 0; i < 2; ++i) {
    if (Wire.available()) {
      data[i] = Wire.read();
    }
  }
  int16_t temp = int(data[0]);
  temp = temp * 256;
  temp = temp + (unsigned int)(data[1]);
  temp = temp / 16;
  float T = 0;
  T = 256.0 * (temp + 2048.0) / 4095.0 - 128;
  return T;
}

int MUA::configurarResolucionTMP(int bits)
{
  Wire.beginTransmission(int(TMP100)); //Dirección del TMP100
  Wire.write(0x01);
  if(bits==9)      { Wire.write(0b00000001); return Wire.endTransmission(true); }
  else if(bits==10){ Wire.write(0b00100001); return Wire.endTransmission(true); }
  else if(bits==11){ Wire.write(0b01000001); return Wire.endTransmission(true); }
  else if(bits==12){ Wire.write(0b01100001); return Wire.endTransmission(true); }
  else { Wire.endTransmission(true); return -1; }
}

int MUA::escribirPotenciometro(uint16_t valor)
{
  if(valor>256) {valor=256;}
  Wire.beginTransmission(MCP4561); //Dirección del MCP4561
  byte DH = valor/256;
  byte D1 = 0b00000000 or DH;
  byte D2 = byte(valor);
  //Serial.println(D1,BIN);
  //Serial.println(D2,BIN);
  Wire.write(D1);
  Wire.write(D2);
  return Wire.endTransmission(true);
}

int MUA::escribirMAX(uint8_t val, uint8_t nCS)
{
  SPI.beginTransaction(SPISettings(1000000, MSBFIRST, SPI_MODE0));
  digitalWrite(nCS,LOW);
  SPI.transfer(val);
  digitalWrite(nCS,HIGH);
  SPI.endTransaction();
  return 0;
}

int MUA::escribirDAC(uint16_t val, uint8_t nCS)
{
  byte byte1 = 0x00;
  byte byte2 = byte(val/256);
  byte byte3 = byte(val);
  SPI.beginTransaction(SPISettings(1000000, MSBFIRST, SPI_MODE1));
  digitalWrite(nCS,LOW);
  SPI.transfer(byte1);
  SPI.transfer(byte2);
  SPI.transfer(byte3);
  digitalWrite(nCS,HIGH);
  SPI.endTransaction();
  return 0;
}

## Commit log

2025-03-27 Archivos de programa de comunicación
2025-03-27 Modelos 3D
    [CarcasaV3.FCStd, CarcasaV3.step, CarcasaV3.stl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]
2025-03-27 Proyecto Placa SiPM
    [MICROFJ-60035-TSV_ONS.step, MICROFJ-60035-TSV_ONS.stl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]
2025-03-27 Placa Unidad Detección
    [01_Polarizacion.kicad_sch, 02_Amplificacion.kicad_sch, 03_Comparación.kicad_sch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]
2025-07-07 Threading and CNC adjustments.
    [CarcasaV3.FCStd, CarcasaV3.step, CarcasaV3.stl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]
2025-07-07 Dual Pot added.
    [03_Comparación.kicad_sch, 04_GenVref.kicad_sch, Placa_DetectorParticulas.kicad_pcb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]
2025-07-08 Added hysteresis in comparator.
    [03_Comparación.kicad_sch, Placa_DetectorParticulas.kicad_pcb]
